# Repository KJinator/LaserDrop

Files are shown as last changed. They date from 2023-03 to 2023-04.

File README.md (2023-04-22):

# LaserDrop
KJ Newman, Anju Ito, and Roger Lacson Senior Capstone

## C
To compile code, run:
gcc send_library.c receive_library.c queue.c protocol_1024.c -o test -Wall -Wextra -lftd2xx -lpthread -lobjc -framework IOKit -framework CoreFoundation -Wl,-rpath /usr/local/lib -L/usr/local/lib

## FPGA Configuration
(More details can be found in output_files/FinalVDuty)
- KEY0: RESET
- SW[0]: (ON) Turns the whole FPGA on/off.
- SW[1]: (OFF) Constant Receive Mode. For debug. Will send over handshaking, etc. bits.
- SW[2]: (OFF) Turn on to toggle both lasers.
- SW[3]: (OFF) Turning on forces both lasers to turn on. Will not turn off until switch turned off.
- SW[4]: (OFF) Turn on to disable ambient light filtering.
- SW[8:5]: (0100 for 6.25MHz transmission; 1000 for 3.125MHz) Sets clock divider to be used for laser transmission. Set MSB (left) to LSB (right), in binary.
- SW[9]: (OFF) Debug Mode. Ask Anju for details. Some bits overwritten to send FPGA information.
- HEX0/1: Last byte sent to FTDI chip.
- HEX2/3: Last byte received over lasers.
- HEX4/5: Last byte sent over lasers.

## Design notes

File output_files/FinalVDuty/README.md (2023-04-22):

# Full System V0

## Features/Quirks:
- Sends data over lasers. Will handshake at beginning of every packet.
- ** Transmitter only sends data in 1kB chunks ** Afterwards, it rehandshakes
  to transmit next packet.
- ** Receiver only sends over data in 1kB chunks ** If bytes in buffer is less
  than 1kB and times out, it fills the rest with 0x01.
- There is a 128kB buffer on both the receiver and sender side.
- I think the FPGA should be able to handle read/write of 128kB through USB at
  once.
- Once FPGA thinks it saw a message on the FTDI, it will keep transmission.
  You would need to press Reset (KEY0) to restart. This may happen on startup,
  because start behavior can be weird on FTDI and FPGA side.

## CONFIGURATIONS:
- KEY0: RESET

- SW[0]: (ON)
    Turns the whole FPGA on/off.
- SW[1]: (OFF)
    Constant Receive Mode. For debug. Will send over handshaking, etc. bits.
- SW[2]: (OFF)
    Turn on to toggle both lasers.
- SW[3]: (OFF)
    Turning on forces both lasers to turn on. Will not turn off until switch
    turned off.
- SW[4]: (OFF)
    Turn on to disable ambient light filtering. 
- SW[8:5]: (0100 for 6.25MHz transmission; 1000 for 3.125MHz)
    Sets clock divider to be used for laser transmission. Set MSB (left) to
    LSB (right), in binary.
- SW[9]: (OFF)
    Debug Mode. Ask Anju for details. Some bits overwritten to send FPGA
    information.

- HEX0/1: Last byte sent to FTDI chip.
- HEX2/3: Last byte received over lasers.
- HEX4/5: Last byte sent over lasers.

- LEDR[1:0]
    Laser_TX2/1, respectively.
- LEDR[4] 
    tx_done. Flashes for a clock cycle whenever a byte is sent over UART.
- LEDR[5]
    data_valid. Flashes for a clock cycle whenever a byte is received over UART.
- LEDR[6]
    clock_start. GPIO[33]. Ask Anju for details. Used for timer counter to get
    metrics.
- LEDR[8]
    laser_rx. What it sees on the laser receiver line.
- LEDR[9]
    wrq_empty. Lights up whenever 1k buffer on receiver is empty.

## FPGA Programming
- Open the .bat file, and press 3. Wait for it to program. Click red button
  twice to start it up.

## Wire configuration (without PCB)
- GND to GND
- All ACBUS and ADBUS pins connected from PCB to FPGA
- Laser_TX2 to Laser_RX, Laser_RX to LASER_TX2
- GPIO[33] (TX) to GPIO[35] (RX) - only needed when doing counter metrics

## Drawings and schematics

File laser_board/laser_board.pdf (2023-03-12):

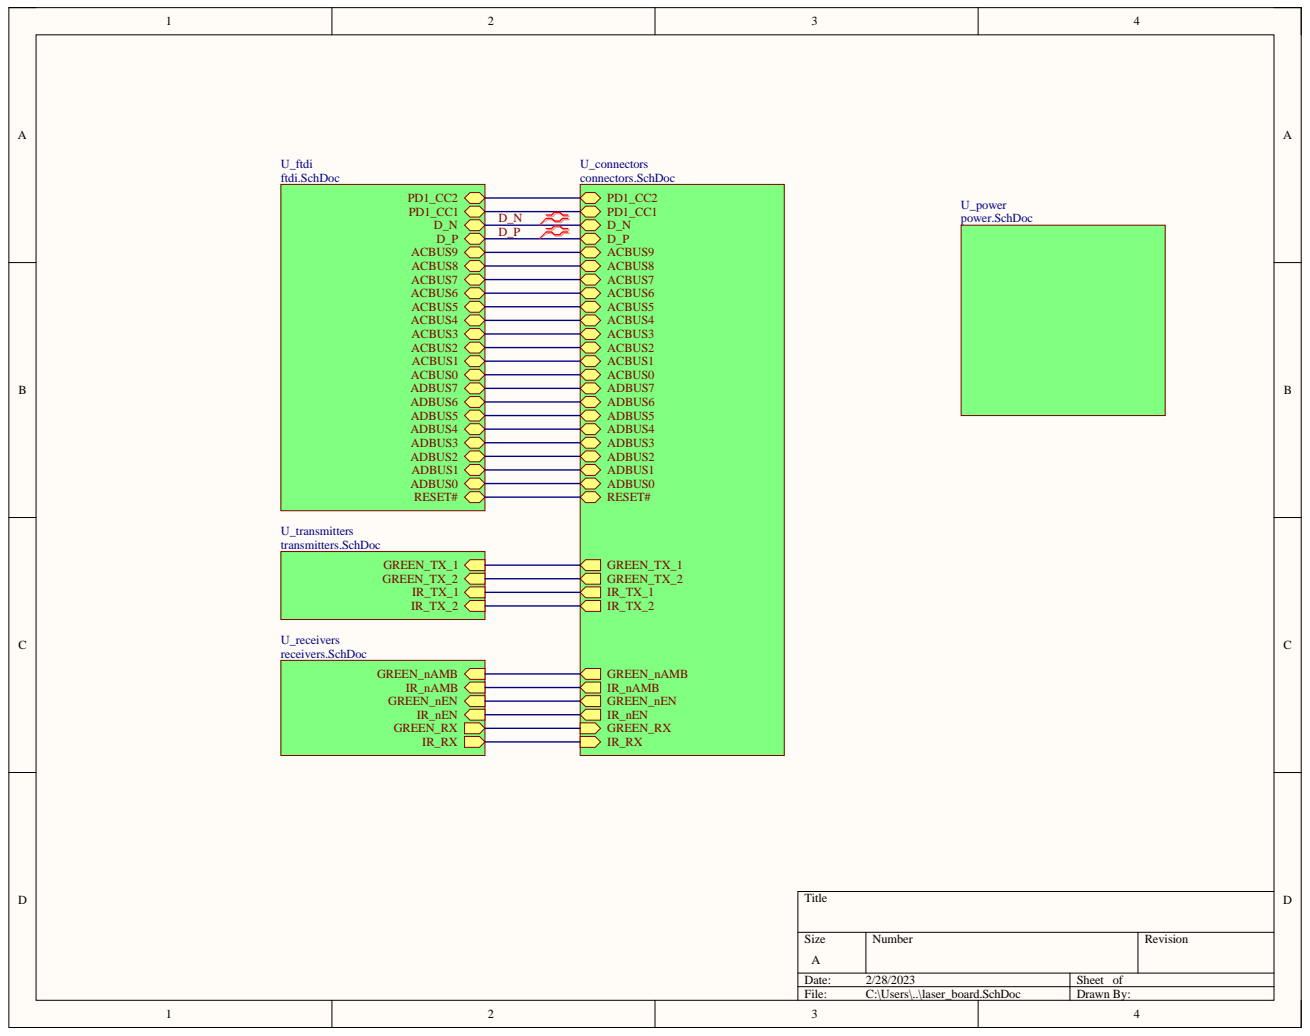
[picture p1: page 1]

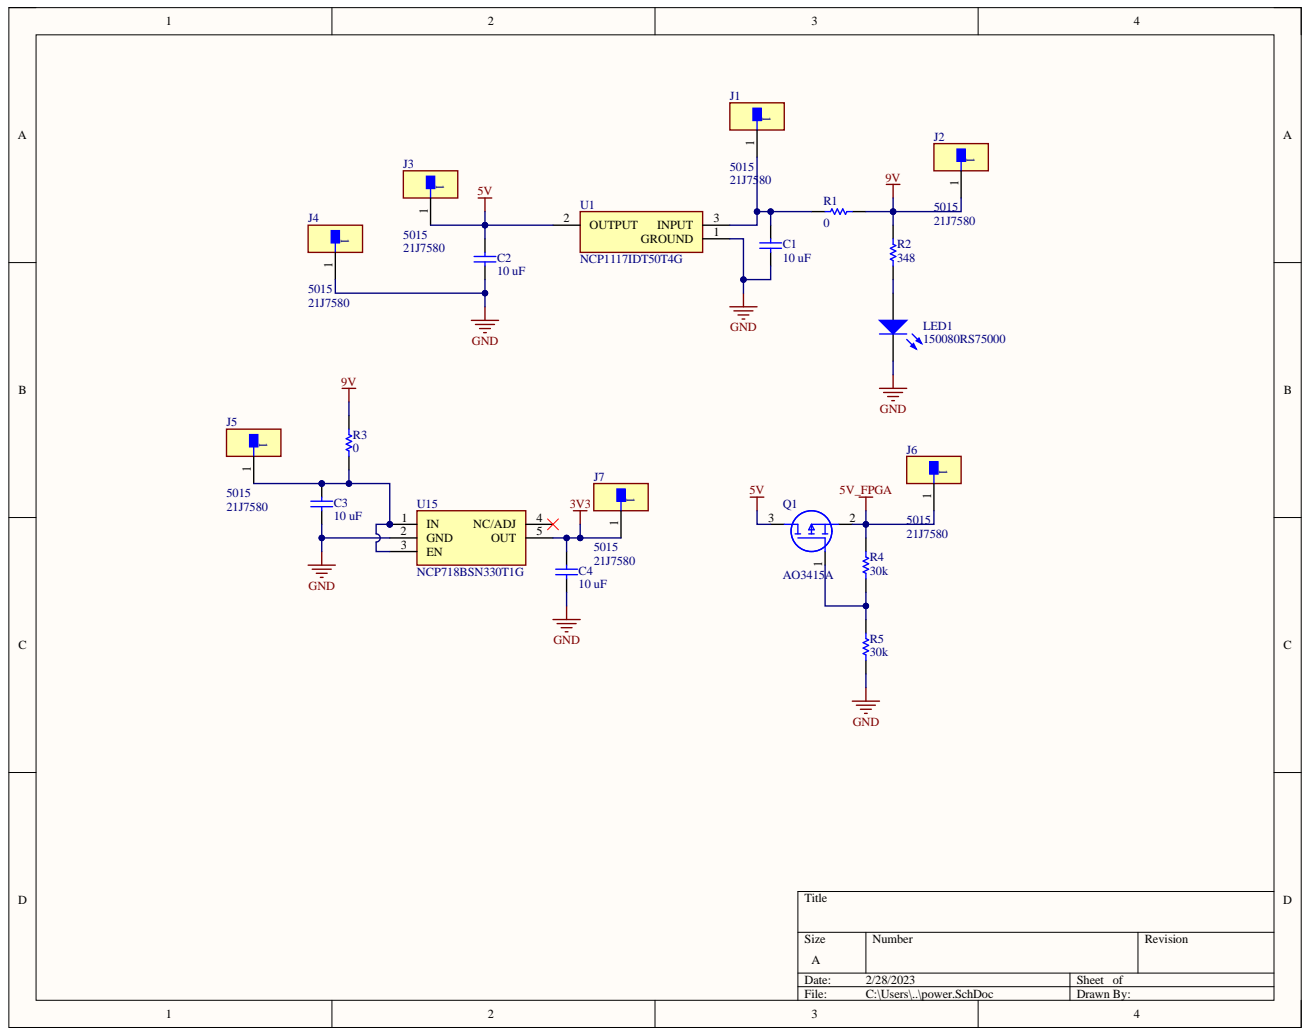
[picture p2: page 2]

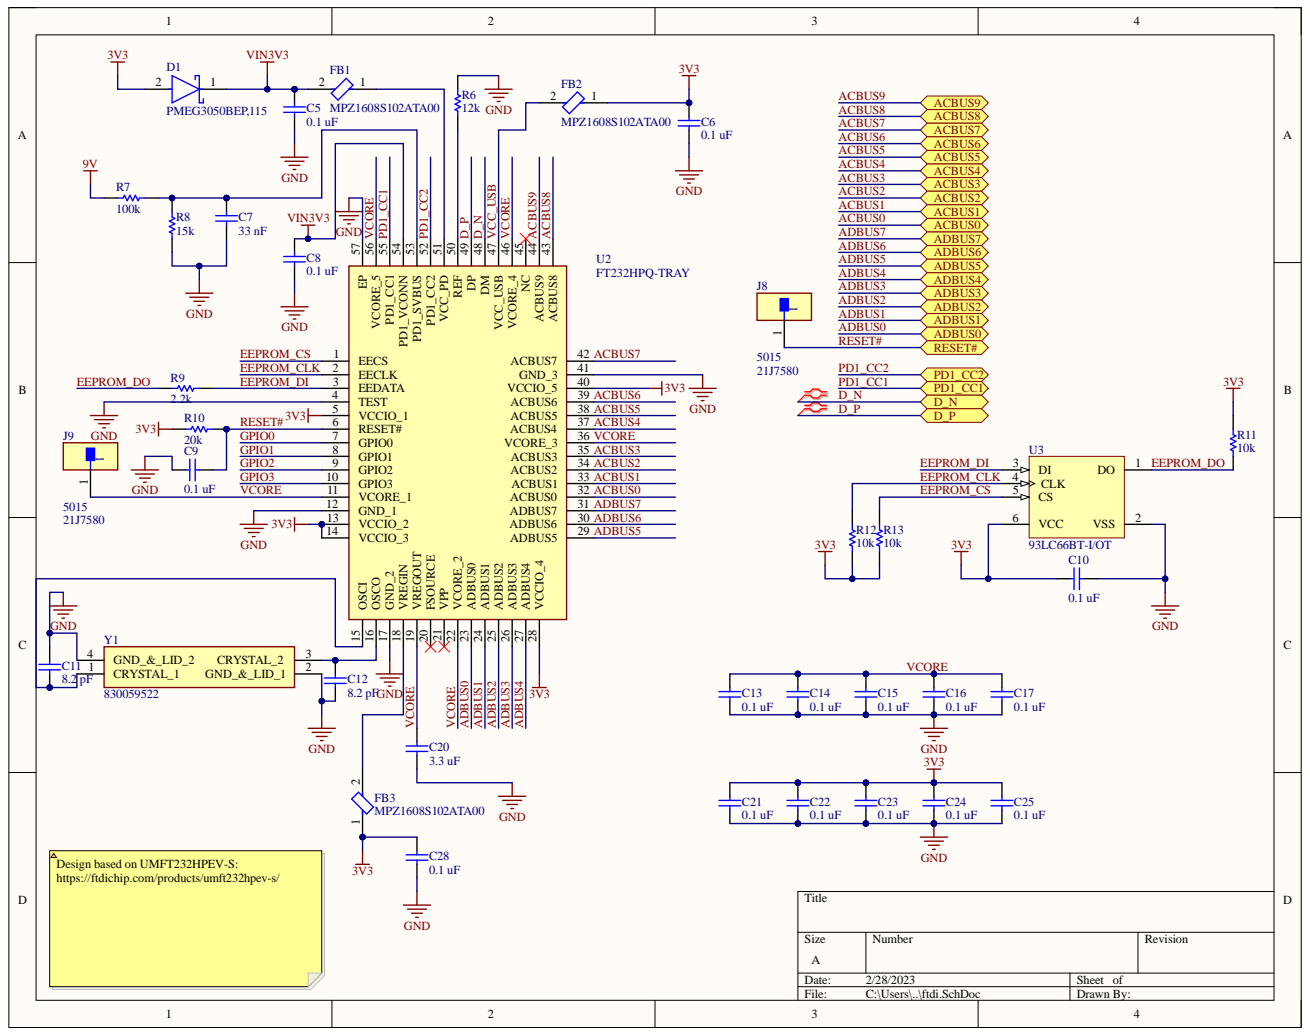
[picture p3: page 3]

Design based on UMFT232HPEV-S:
https://ftdichip.com/product

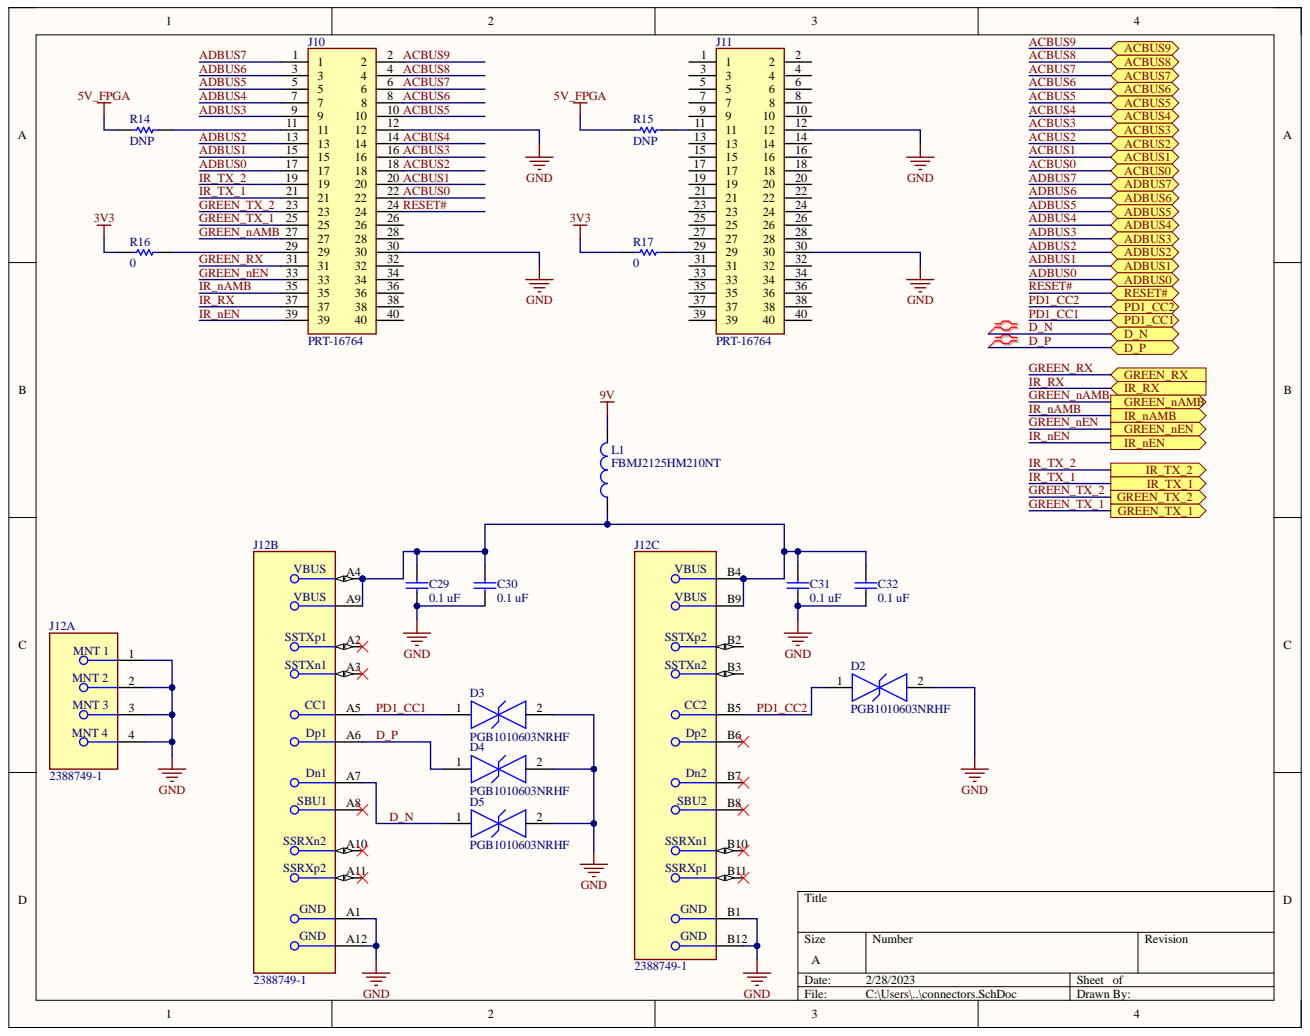
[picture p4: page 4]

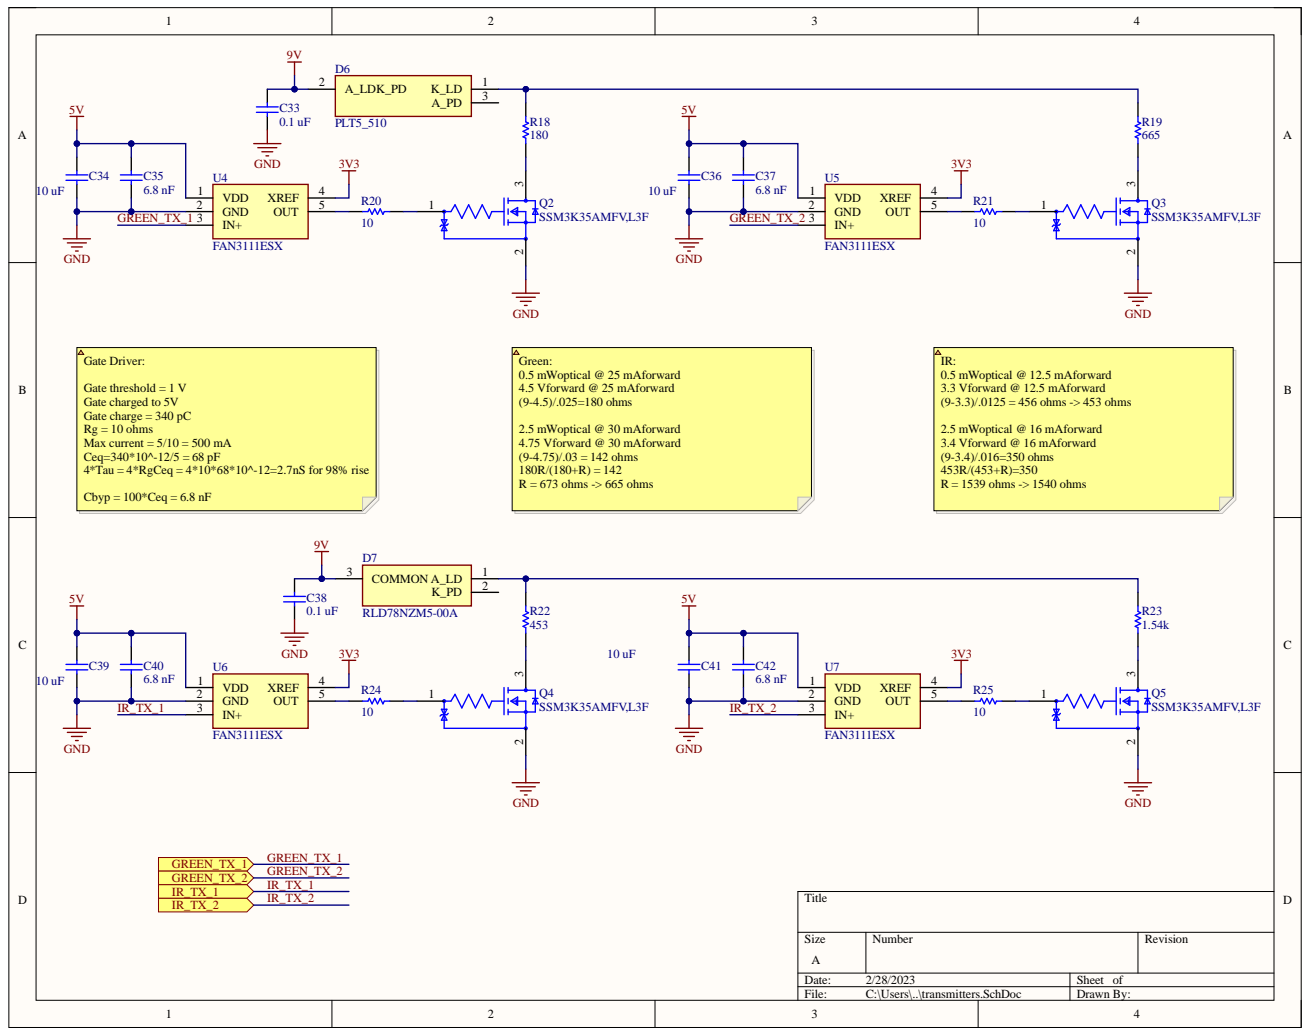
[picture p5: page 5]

Gate threshold = 1 V
Gate charged to 5V
Gate charge = 340 pC
Rg = 10 ohms
Max current = 5/10 = 500 mA
Ceq=340*10^-12/5 = 68 pF
4*Tau = 4*RgCeq = 4*10*68*10^-12=2.7nS for 98% rise

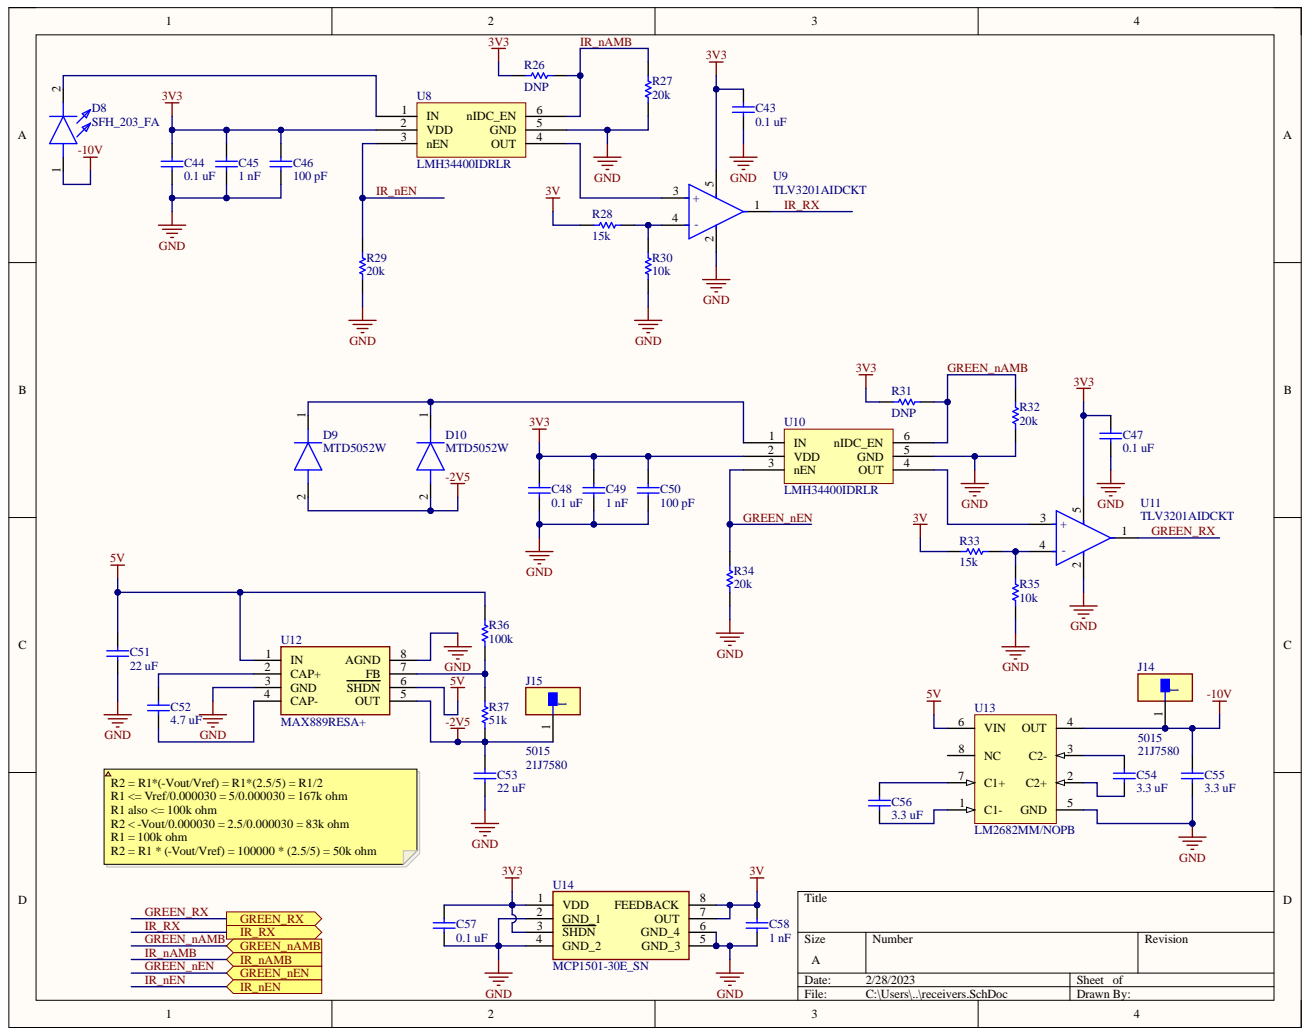
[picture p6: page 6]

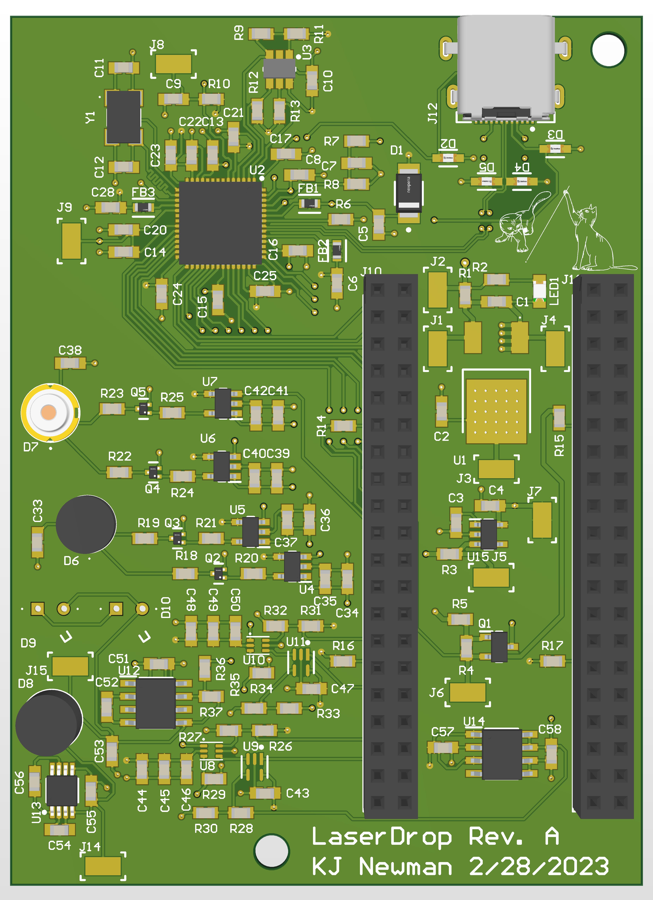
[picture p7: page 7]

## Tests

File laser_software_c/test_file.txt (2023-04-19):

123456789123456789123456789123456789123456789123456789123456789123456789123456789123456789123456789123456789123456789123456789123456789123456789123456789123456789123456789123456789123456789123456789123456789123456789123456789123456789123456789123456789123456789123456789123456789123456789123456789123456789123456789123456789123456789123456789123456789123456789123456789123456789123456789123456789123456789123456789123456789123456789123456789123456789123456789123456789123456789123456789123456789123456789123456789123456789123456789123456789123456789123456789123456789123456789123456789123456789123456789123456789123456789123456789123456789123456789123456789123456789123456789123456789123456789123456789123456789123456789123456789123456789123456789123456789123456789123456789123456789123456789123456789123456789123456789123456789123456789123456789123456789123456789123456789123456789123456789123456789123456789123456789123456789123456789123456789123456789123456789123456789123456789123456789123456789123456789123456789123456789123456789123456789123456789123456789123456789123456789123456789123456789123456789123456789123456789123456789123456789123456789123456789123456789123456789123456789123456789123456789123456789123456789123456789123456789123456789123456789123456789123456789123456789123456789123456789123456789123456789123456789123456789123456789123456789123456789123456789123456789123456789123456789123456789123456789123456789123456789123456789123456789123456789123456789123456789123456789123456789123456789123456789123456789123456789123456789123456789123456789123456789123456789123456789123456789123456789123456789123456789123456789123456789123456789123456789123456789123456789123456789123456789123456789123456789123456789123456789123456789123456789123456789123456789123456789123456789123456789123456789123456789123456789123456789123456789123456789123456789123456789123456789123456789123456789123456789123456789123456789123456789123456789123456789123456789123456789123456789123456789123456789123456789123456789123456789123456789123456789123456789123456789123456789123456789123456789123456789123456789123456789123456789123456789123456789123456789123456789123456789123456789123456789123456789123456789123456789123456789123456789123456789123456789123456789123456789123456789123456789123456789123456789123456789123456789123456789123456789123456789123456789123456789123456789123456789123456789123456789123456789123456789123456789123456789123456789123456789123456789123456789123456789123456789123456789123456789123456789123456789123456789123456789123456789123456789123456789123456789123456789123456789123456789123456789123456789123456789123456789123456789123456789123456789123456789123456789123456789123456789123456789123456789123456789123456789123456789123456789123456789123456789123456789123456789123456789123456789123456789123456789123456789123456789123456789123456789123456789123456789123456789123456789123456789123456789123456789123456789123456789123456789123456789123456789123456789123456789123456789123456789123456789123456789123456789123456789123456789123456789123456789123456789123456789123456789123456789123456789123456789123456789123456789123456789123456789123456789123456789123456789123456789123456789123456789123456789123456789123456789123456789123456789123456789123456789123456789123456789123456789123456789123456789123456789123456789123456789123456789123456789123456789123456789123456789123456789123456789123456789123456789123456789123456789123456789123456789123456789123456789123456789123456789123456789123456789123456789123456789123456789123456789123456789123456789123456789123456789123456789123456789123456789123456789123456789123456789123456789123456789123456789123456789123456789123456789123456789123456789123456789123456789123456789123456789123456789123456789123456789123456789123456789123456789123456789123456789123456789123456789123456789123456789123456789123456789123456789123456789123456789123456789123456789123456789123456789123456789123456789123456789123456789123456789123456789123456789123456789123456789123456789123456789123456789123456789123456789123456789123456789123456789123456789123456789123456789123456789123456789123456789123456789123456789123456789123456789123456789123456789123456789123456789123456789123456789123456789123456789123456789123456789123456789123456789123456789123456789123456789123456789123456789123456789123456789123456789123456789123456789123456789123456789123456789123456789123456789123456789123456789123456789123456789123456789123456789123456789123456789123456789123456789123456789123456789123456789123456789123456789123456789123456789123456789123456789123456789123456789123456789123456789123456789123456789123456789123456789123456789123456789123456789123456789123456789123456789123456789123456789123456789123456789123456789123456789123456789123456789123456789123456789123456789123456789123456789123456789123456789123456789123456789123456789123456789123456789123456789123456789123456789123456789123456789123456789123456789123456789123456789123456789123456789123456789123456789123456789123456789123456789123456789123456789123456789123456789123456789123456789123456789123456789123456789123456789123456789123456789123456789123456789123456789123456789123456789123456789123456789123456789123456789123456789123456789123456789123456789123456789123456789123456789123456789123456789123456789123456789123456789123456789123456789123456789123456789123456789123456789123456789123456789123456789123456789123456789123456789123456789123456789123456789123456789123456789123456789123456789123456789123456789123456789123456789123456789123456789123456789123456789123456789123456789123456789123456789123456789123456789123456789123456789123456789123456789123456789123456789123456789123456789123456789123456789123456789123456789123456789123456789123456789123456789123456789123456789123456789123456789123456789123456789123456789123456789123456789123456789123456789123456789123456789123456789123456789123456789123456789123456789123456789123456789123456789123456789123456789123456789123456789123456789123456789123456789123456789123456789123456789123456789123456789123456789123456789123456789123456789123456789123456789123456789123456789123456789123456789123456789123456789123456789123456789123456789123456789123456789123456789123456789123456789123456789123456789123456789123456789123456789123456789123456789123456789123456789123456789123456789123456789123456789123456789123456789123456789123456789123456789123456789123456789123456789123456789123456789123456789123456789123456789123456789123456789123456789123456789123456789123456789123456789123456789123456789123456789123456789123456789123456789123456789123456789123456789123456789123456789123456789123456789123456789123456789123456789123456789123456789123456789123456789123456789123456789123456789123456789123456789123456789123456789123456789123456789123456789123456789123456789123456789123456789123456789123456789123456789123456789123456789123456789123456789123456789123456789123456789123456789123456789123456789123456789123456789123456789123456789123456789123456789123456789123456789123456789123456789123456789123456789123456789123456789123456789123456789123456789123456789123456789123456789123456789123456789123456789123456789123456789123456789123456789123456789123456789123456789123456789123456789123456789123456789123456789123456789123456789123456789123456789123456789123456789123456789123456789123456789123456789123456789123456789123456789123456789123456789123456789123456789123456789123456789123456789123456789123456789123456789123456789123456789123456789123456789123456789123456789123456789123456789123456789123456789123456789123456789123456789123456789123456789123456789123456789123456789123456789123456789123456789123456789123456789123456789123456789123456789123456789123456789123456789123456789123456789123456789123456789123456789123456789123456789123456789123456789123456789123456789123456789123456789123456789123456789123456789123456789123456789123456789123456789123456789123456789123456789123456789123456789123456789123456789123456789123456789123456789123456789123456789123456789123456789123456789123456789123456789123456789123456789123456789123456789123456789123456789123456789123456789123456789123456789123456789123456789123456789123456789123456789123456789123456789123456789123456789123456789123456789123456789123456789123456789123456789123456789123456789123456789123456789123456789123456789123456789123456789123456789123456789123456789123456789123456789123456789123456789123456789123456789123456789123456789123456789123456789123456789123456789123456789123456789123456789123456789123456789123456789123456789123456789123456789123456789123456789123456789123456789123456789123456789123456789123456789123456789123456789123456789123456789123456789123456789123456789123456789123456789123456789123456789123456789123456789123456789123456789123456789123456789123456789123456789123456789123456789123456789123456789123456789123456789123456789123456789123456789123456789123456789123456789123456789123456789123456789123456789123456789123456789123456789123456789123456789123456789123456789123456789123456789123456789123456789123456789123456789123456789123456789123456789123456789123456789123456789123456789123456789123456789123456789123456789123456789123456789123456789123456789123456789123456789123456789123456789123456789123456789123456789123456789123456789123456789123456789123456789123456789123456789123456789123456789123456789123456789123456789123456789123456789123456789123456789123456789123456789123456789123456789123456789123456789123456789123456789123456789123456789123456789123456789123456789123456789123456789123456789123456789123456789123456789123456789123456789123456789123456789123456789123456789123456789123456789123456789123456789123456789123456789123456789123456789123456789123456789123456789123456789123456789123456789123456789123456789123456789123456789123456789123456789123456789123456789123456789123456789123456789123456789123456789123456789123456789123456789123456789123456789123456789123456789123456789123456789123456789123456789123456789123456789123456789123456789123456789123456789123456789123456789123456789123456789123456789123456789123456789123456789123456789123456789123456789123456789123456789123456789123456789123456789123456789123456789123456789123456789123456789123456789123456789123456789123456789123456789123456789123456789123456789123456789123456789123456789123456789123456789123456789123456789123456789123456789123456789123456789123456789123456789123456789123456789123456789123456789123456789123456789123456789123456789123456789123456789123456789123456789123456789123456789123456789123456789123456789123456789123456789123456789123456789123456789123456789123456789123456789123456789123456789123456789123456789123456789123456789123456789123456789123456789123456789123456789123456789123456789123456789123456789123456789123456789123456789123456789123456789123456789123456789123456789123456789123456789123456789123456789123456789123456789123456789123456789123456789123456789123456789123456789123456789123456789123456789123456789123456789123456789123456789123456789123456789123456789123456789123456789123456789123456789123456789123456789123456789123456789123456789123456789123456789123456789123456789123456789123456789123456789123456789123456789123456789123456789123456789123456789123456789123456789123456789123456789123456789123456789123456789123456789123456789123456789123456789123456789123456789123456789123456789123456789123456789123456789123456789123456789123456789123456789123456789123456789123456789123456789123456789123456789123456789123456789123456789123456789123456789123456789123456789123456789123456789123456789123456789123456789123456789123456789123456789123456789123456789

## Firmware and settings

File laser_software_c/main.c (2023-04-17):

#include <stdlib.h>
#include <stdio.h>
#include "send_library.h"
#include "ftd2xx.h"
#include <time.h>

/*
int main(int argc, char *argv[]) {
    FT_HANDLE ftHandle;
    FT_STATUS ftStatus;
    DWORD numDevs;
    DWORD dwVID, dwPID;
    DWORD BytesWritten, BytesRecieved;
    dwVID = 0x0403;
    dwPID = 0x6045;

    char TxBuffer[1024];
    char RxBuffer[1024];

    memset(TxBuffer, 0, sizeof(TxBuffer));

    TxBuffer[0] = 9;
    TxBuffer[1] = 2;
    TxBuffer[2] = 3;
    TxBuffer[3] = 4;

    ftStatus = FT_SetVIDPID(dwVID, dwPID);
    
    if (ftStatus != FT_OK) {
        printf("Darn\n\n");
        return 0;
    }

    printf("Device VID = %x; Device PID = %x\n\n", dwVID, dwPID);
    
    ftStatus = FT_OpenEx("USB <-> Serial Converter", FT_OPEN_BY_DESCRIPTION, &ftHandle);

    if(ftStatus != FT_OK) {
        printf("Open Error\n\n");
        return 0;
    }
    FT_SetTimeouts(ftHandle,1000,0);

    ftStatus = FT_Read(ftHandle, RxBuffer, sizeof(RxBuffer), &BytesRecieved);


    // clock_t time_start = clock();
    // ftStatus = FT_Write(ftHandle, TxBuffer, sizeof(TxBuffer), &BytesWritten);
    ftStatus = FT_Write(ftHandle, TxBuffer, 1, &BytesWritten);
    // clock_t time_write = clock();
    if (ftStatus != FT_OK) {
        printf("Write Error\n\n");
        ftStatus = FT_Close(ftHandle);
        if (ftStatus != FT_OK) {
            printf("Close Error \n\n");
        }
        return 0;
    }

    ftStatus = FT_Close(ftHandle);
    if (ftStatus != FT_OK) {
        printf("Close Error \n\n");
    }


    return 0;
} */
 
int main(int argc, char *argv[]) {
    FT_HANDLE ftHandle;
    FT_STATUS ftStatus;
    DWORD numDevs;
    DWORD dwVID, dwPID;
    DWORD BytesWritten, BytesRecieved;
    dwVID = 0x0403;
    dwPID = 0x6045;

    char TxBuffer[1024];
    char RxBuffer[1024];

    memset(TxBuffer, 0, sizeof(TxBuffer));

    TxBuffer[0] = 1;
    TxBuffer[1] = 2;
    TxBuffer[2] = 3;
    TxBuffer[3] = 4;

    ftStatus = FT_SetVIDPID(dwVID, dwPID);
    
    if (ftStatus != FT_OK) {
        printf("Darn\n\n");
        return 0;
    }

    printf("Device VID = %x; Device PID = %x\n\n", dwVID, dwPID);
    
    ftStatus = FT_OpenEx("USB <-> Serial Converter", FT_OPEN_BY_DESCRIPTION, &ftHandle);

    if(ftStatus != FT_OK) {
        printf("Open Error\n\n");
        return 0;
    }

    // ftStatus = FT_SetBaudRate(ftHandle, 500000);

    FT_SetTimeouts(ftHandle,200,0);
    // clock_t time_start = clock();
    // ftStatus = FT_Write(ftHandle, TxBuffer, sizeof(TxBuffer), &BytesWritten);
    ftStatus = FT_Read(ftHandle, RxBuffer, sizeof(RxBuffer), &BytesRecieved);

    ftStatus = FT_SetBaudRate(ftHandle, 1152000);

    for (size_t i = 0; i < 10; i++) {
        TxBuffer[0]++;
        clock_t time_start = clock();
        ftStatus = FT_Write(ftHandle, TxBuffer, 2, &BytesWritten);
        clock_t time_write = clock();
        if (ftStatus != FT_OK) {
            printf("Write Error\n\n");
            ftStatus = FT_Close(ftHandle);
            if (ftStatus != FT_OK) {
                printf("Close Error \n\n");
            }
            return 0;
        }

        // printf("Write sucess!!!\n\n");
        
        clock_t time_read_start = clock();
        ftStatus = FT_Read(ftHandle, RxBuffer, 1000, &BytesRecieved);
        clock_t time_end = clock();
        
        if (ftStatus != FT_OK) {
            printf("Read Error\n\n");
            ftStatus = FT_Close(ftHandle);
            if (ftStatus != FT_OK) {
                printf("Close Error \n\n");
            }
            return 0;
        }

        // printf("Bytes Read = %d, Bytes Written = %d\n\n", RxBuffer[0], TxBuffer[0]);
        printf("Bytes Read: %d %d, Bytes Written: %d %d\n\n", RxBuffer[0], RxBuffer[1], TxBuffer[0], TxBuffer[1]);
        printf("Time = %lf\n\n", ((double)(time_end - time_start))/CLOCKS_PER_SEC);
        printf("Time Write = %lf, Time Read = %lf\n\n", ((double)(time_write - time_start))/CLOCKS_PER_SEC, ((double)(time_end - time_read_start))/CLOCKS_PER_SEC);
    }

    ftStatus = FT_Close(ftHandle);
    if (ftStatus != FT_OK) {
        printf("Close Error \n\n");
    }


    return 0;
}

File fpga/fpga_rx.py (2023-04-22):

import atexit
import time
import serial
from common import send

s = serial.Serial('COM9', timeout=1)
atexit.register(s.close)

expected = send

# Read
while True:
    read = s.read(1024).hex()
    num_read = len(read) // 2
    print(f"Read {read} ({num_read} bytes)")

    # if (num_read > 0):
    #     print(f"Read {read} ({num_read} bytes)")
    #     print("Num errors: ")

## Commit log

2023-02-10 add pcb files
    [laser_board.PrjPcb, laser_board.SchDoc]
2023-02-10 resistor calculations
    [laser_board.SchDoc]
2023-02-10 create discrete file
    [discreteTx.SchDoc, fiberoptic.SchDoc, laser_board.PrjPcb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]
2023-02-13 efficiency of green laser
    [discreteTx.SchDoc]
2023-02-18 added fpga connectors
    [discreteTx.SchDoc, fiberoptic.SchDoc, laser_board.PrjPcb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]
2023-02-18 Added all active components
    [TIA.PcbLib, TIA.SchLib, connectors.SchDog.SchDoc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]
2023-02-18 usb connector added
    [connectors.SchDoc, connectors.SchDog.SchDoc, laser_board.PrjPcb]
2023-02-19 complete transmitters
    [ftdi.SchDoc, laser_board.SchDoc, receivers.SchDoc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]
2023-02-19 receivers added
    [laser_board.SchDoc, receivers.SchDoc, transmitters.SchDoc]
2023-02-20 added test points
    [ftdi.SchDoc, laser_board.PrjPcb, laser_board.SchDoc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]
2023-02-20 complete except fpga pinout
    [connectors.SchDoc, ftdi.SchDoc, laser_board.SchDoc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]
2023-02-22 review changes done
    [connectors.SchDoc, laser_board.SchDoc, receivers.SchDoc]
2023-02-24 annotated schematic
    [laser_board.PrjPcb]
2023-02-25 component values finalized
    [ftdi.SchDoc, laser_board.PrjPcb, power.SchDoc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]
2023-02-26 output pdf
    [laser_board.PrjPcb, transmitters.SchDoc]
2023-02-27 components added to layout
    [connectors.SchDoc, laser_board.PcbDoc, laser_board.PrjPcb]
2023-02-27 board shape, layer stackup, and rules imported
    [laser_board.PcbDoc]
2023-02-27 usb controlled impedance set up
    [connectors.SchDoc, ftdi.SchDoc, laser_board.PcbDoc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]
2023-02-27 usb traces smaller to fit in connector
    [laser_board.PcbDoc]
2023-02-27 usb connector routed
    [connectors.SchDoc, laser_board.PcbDoc, receivers.SchDoc]
2023-02-27 correct fpga connector
    [connectors.SchDoc, laser_board.PcbDoc]
2023-02-28 created real board outline
    [laser_board.PcbDoc]
2023-02-28 half of ftdi chip routed
    [laser_board.PcbDoc]
2023-02-28 ftdi routed by itself
    [laser_board.PcbDoc]
2023-02-28 ftdi routing complete
    [connectors.SchDoc, ftdi.SchDoc, laser_board.PcbDoc]
2023-02-28 change layer order
    [laser_board.PcbDoc]
2023-02-28 layer stackup: sig+pwr, gnd, gnd, sig+pwr
    [laser_board.PcbDoc]
2023-02-28 usb connector rotated
    [laser_board.PcbDoc, receivers.SchDoc]
2023-02-28 receivers routed
    [connectors.SchDoc, receivers.SchDoc, transmitters.SchDoc]
2023-02-28 power routed
    [power.SchDoc]
2023-02-28 lasers placed
2023-02-28 lasers finalized
2023-02-28 all except 9V routed
2023-02-28 DRC passes
    [laser_board.PrjPcb]
2023-03-01 generated fabrication documents
    [laser_board.GBL, laser_board.GBO, laser_board.GBP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]
2023-03-01 added pcb 3d print
    [laser_board.PrjPcb]
2023-03-12 Wrote transmitter laser code
    [c5_pin_model_dump.txt]
2023-03-15 MOdified Laser.sv so that it looks for start and stop bit
2023-03-15 Imported pin assignments from default
2023-03-15 Wrote transmitter side of FSM just for nextState. Pin assignment GPIO added in so compilation throws error. Made it so that clockDivider uses a base instead. Declared LaserDrop that handles main FSM
2023-03-15 Wrote transmitter side of FSM just for nextState. Pin assignment GPIO added in and fixed in code. Made it so that clockDivider uses a base instead. Declared LaserDrop that handles main FSM
2023-03-17 Works with correct pin configuration for board
2023-03-18 Modified Laser to allow for single transmission. Doesn't work
2023-03-18 Code modified to support transmission over 1 laser. Need to uncomment/comment to use
2023-03-19 Working version. Use SW[1] to switch between simultaneous transmission
2023-03-21 Laser TB written
2023-04-02 Add Echo and create memory
    [c5_pin_model_dump.txt]
2023-04-03 Change enable pin
2023-04-05 Echo works with multiple data on lasers
2023-04-07 Reverted Laser.sv
2023-04-11 FTDI Chip fixed. Laser transmission may not work
2023-04-12 Add flip flops to laser inputs. Half speed with flip flop in outputs
2023-04-16 Add switch to enable disable 1024 read
2023-04-17 Test Files for transmitting between devices
2023-04-18 Fix minor compilation errors
    [fpga_rx.py]
2023-04-18 fixed compilation and identification of boards
2023-04-20 Seemingly function protocol_1024.c file with working error queue implementation. Includes own test case for testing error queue.
2023-04-20 Cleaned up code, deleting unused variables, removing unnecessary comments and print statements, and including the test case for error queue work.
2023-04-25 removed print statements
2023-04-27 Implemented the new form of handshaking. Still needs to be tested. Also implemented error handling in case an interruption occurs and certain packets are not received. All this needs to be tested
2023-05-01 added ability to select which device is used
